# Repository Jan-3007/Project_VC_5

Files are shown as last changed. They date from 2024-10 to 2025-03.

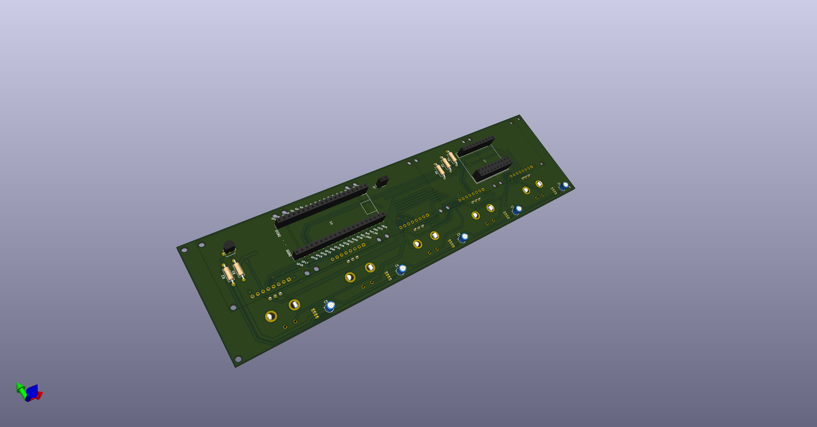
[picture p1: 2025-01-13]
Hardware/schematic/VC5_3D_model_v2.png

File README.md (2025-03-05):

# Project VC 5

Note: This project is the base for my upcoming project VC 5 and won't be updated anymore. Please see ... for an up-to-date version.

## General description
The aim of this project is to create an external device, which allows the user to adjust a variety of settings (e.g. volume, display brightness, settings within a program, ...) on a host PC. 

## Hardware
A number of rotaries are available as input (number set to 5 within the config file of this project) and LED's and displays to show any kind of status.
The schematic for the device can be found at _Harware/schematic_.

## Software
The software consists of two parts.

### 1. Firmware
The firmware is written for the Raspberry Pi RP2040. It communicates via USB with the host PC. The firmware only transmits data from the rotaries to the host PC and executes commands from the host PC. These commands can for example set the color of the LED and change the content shown on the displays.

### 2. PC application
  The PC application (only Windows) acts as the executing intelligence. It takes the data from the rotaries and processes it. In this case, as a demo, the volume of five different artificial audio channels is controlled. The application can also send commands to the device to e.g. set the LED color or write information on the displays.

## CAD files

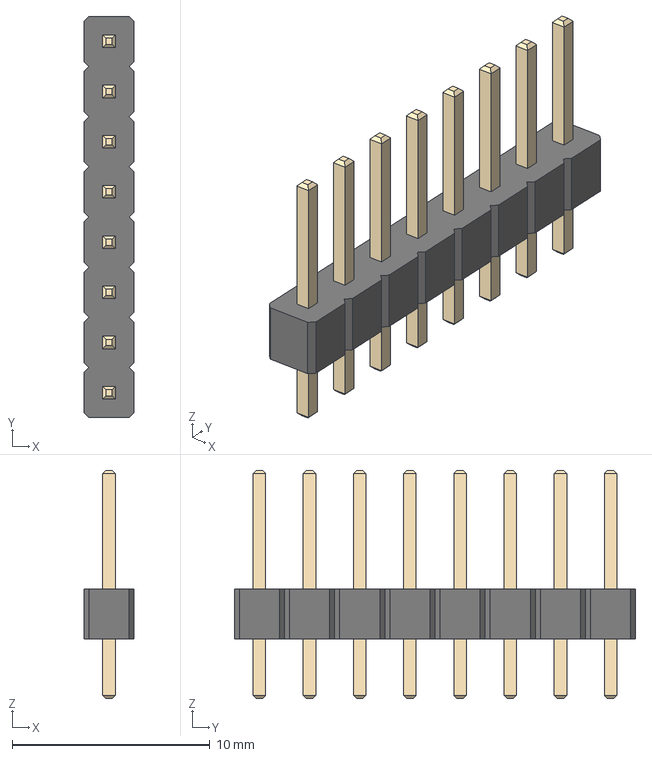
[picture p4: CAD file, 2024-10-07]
Hardware/3D_model/Display_PinHeader_1x08_P2.54mm_Vertical.step
2.54 x 20.3 x 11.5 mm

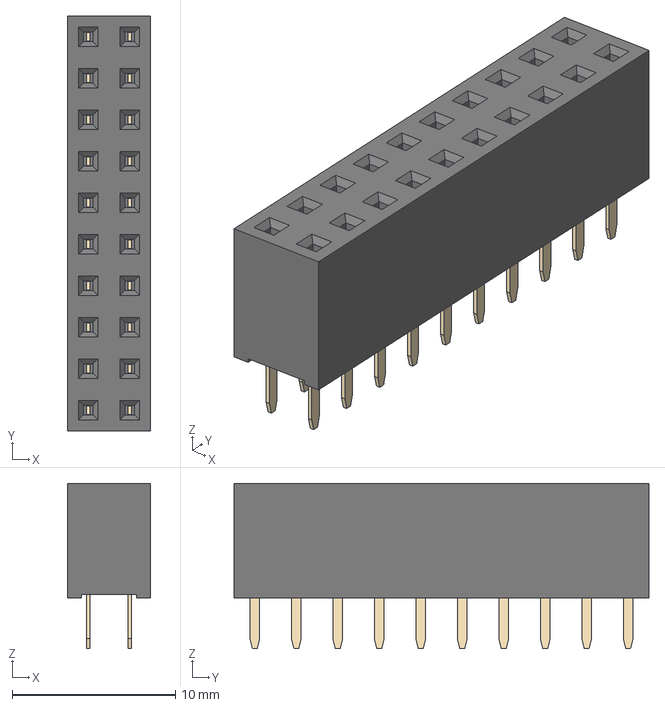
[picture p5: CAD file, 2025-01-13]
Hardware/schematic/VC5_schematic/PinSocket_2x10_P2.54mm_Vertical.step
5.08 x 25.4 x 10.1 mm

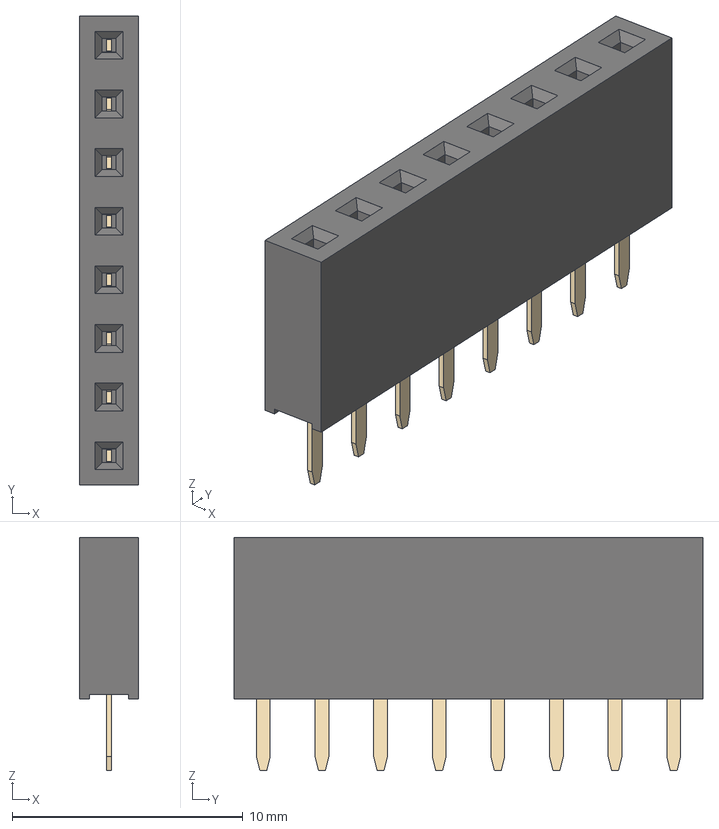
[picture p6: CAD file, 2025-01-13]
Hardware/schematic/VC5_schematic/PinSocket_1x08_P2.54mm_Vertical.step
2.54 x 20.3 x 10.1 mm

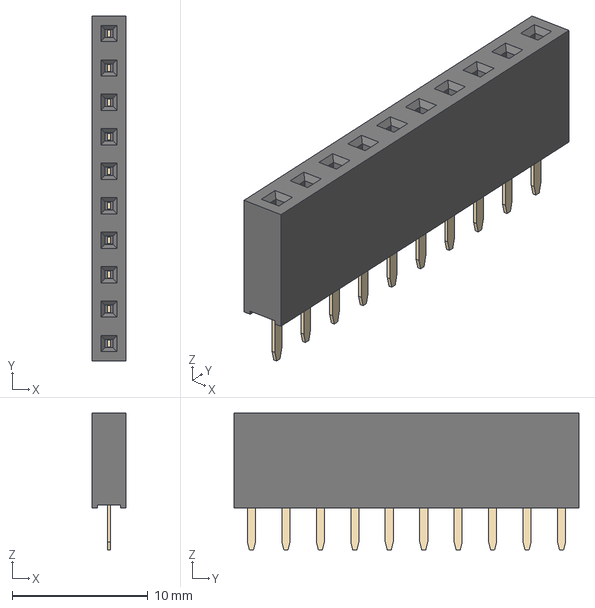
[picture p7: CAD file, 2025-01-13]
Hardware/schematic/VC5_schematic/PinSocket_1x10_P2.54mm_Vertical.step
2.54 x 25.4 x 10.1 mm

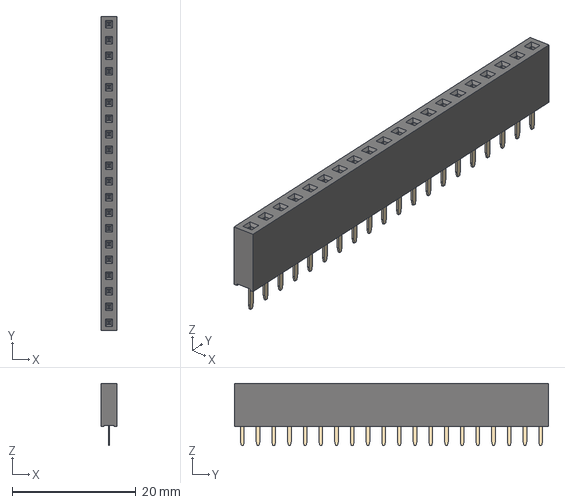
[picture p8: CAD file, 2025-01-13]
Hardware/schematic/VC5_schematic/PinSocket_1x20_P2.54mm_Vertical.step
2.54 x 50.8 x 10.1 mm

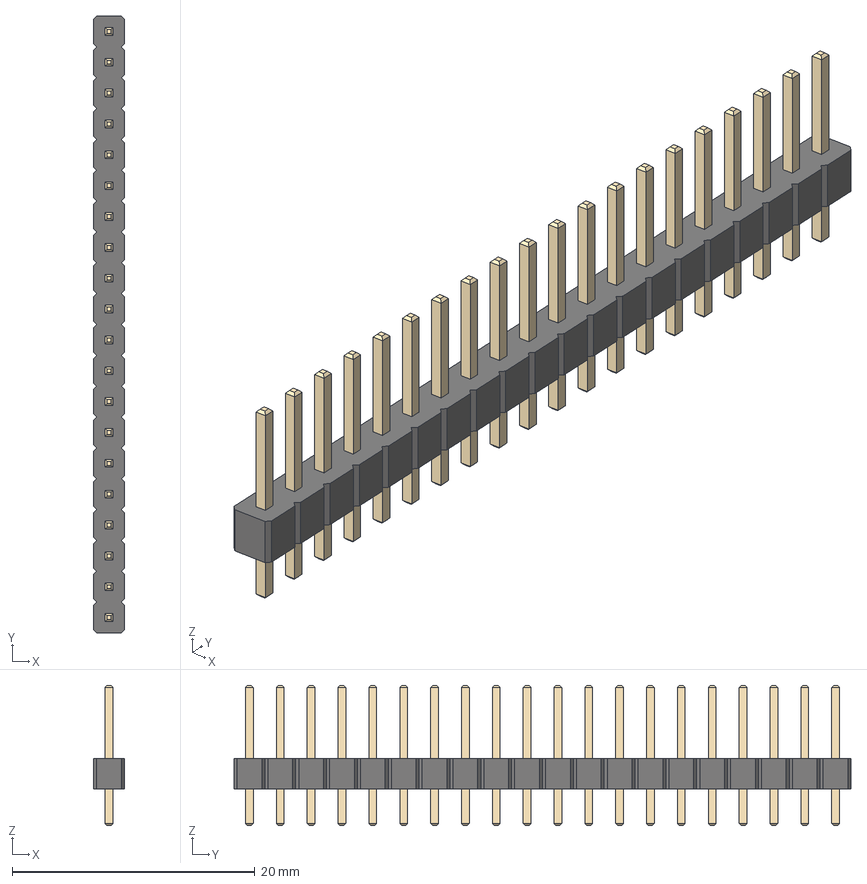
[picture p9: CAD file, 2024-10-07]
Hardware/schematic/VC5_schematic/Pico_PinHeader_1x20_P2.54mm_Vertical.step
2.54 x 50.8 x 11.5 mm

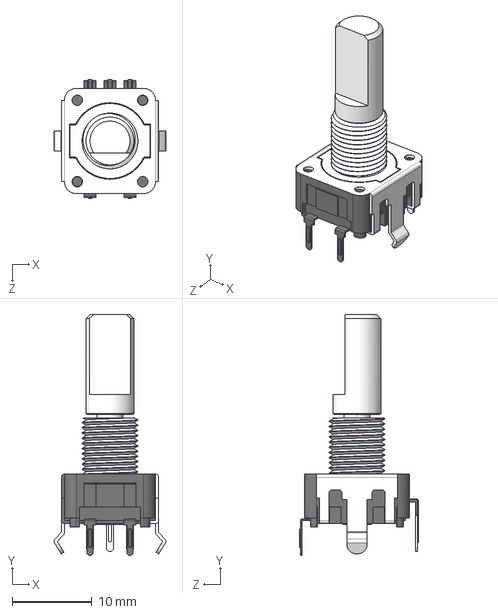
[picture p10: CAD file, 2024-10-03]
Hardware/schematic/VC5_schematic/PEC11R-4220F-S0024.stp
14.0 x 30.2 x 14.9 mm

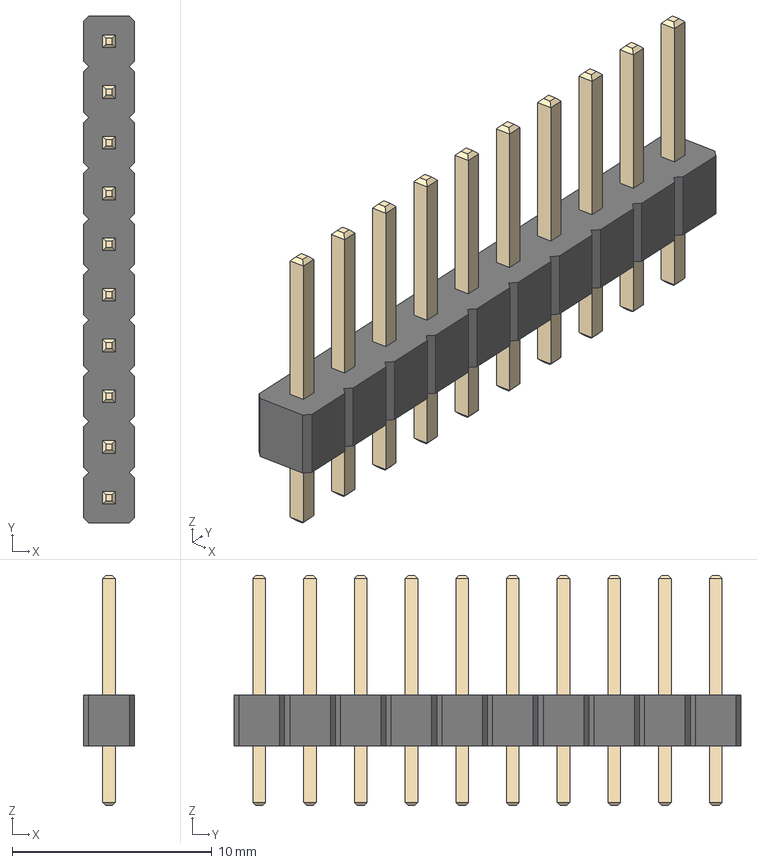
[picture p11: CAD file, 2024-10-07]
Hardware/schematic/VC5_schematic/MCP23017_PinHeader_1x10_P2.54mm_Vertical.step
2.54 x 25.4 x 11.5 mm

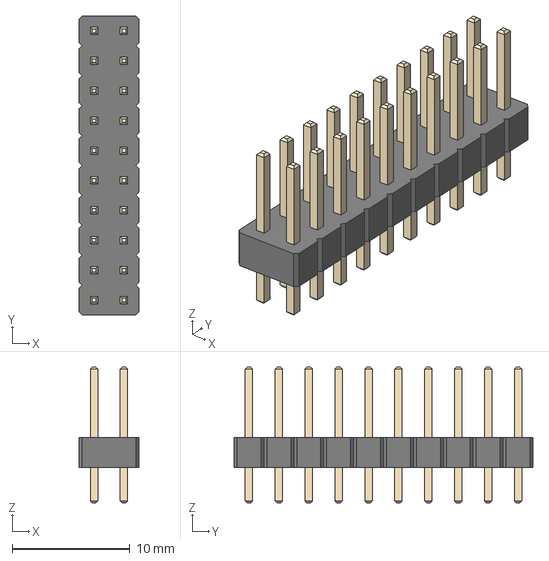
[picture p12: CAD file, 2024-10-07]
Hardware/schematic/VC5_schematic/MCP23017_PinHeader_2x10_P2.54mm_Vertical.step
5.08 x 25.4 x 11.5 mm

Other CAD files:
Hardware/schematic/VC5_schematic/Bourns/PEC11R-4220F-S0024/Allegro/pec11r4220fs0024.psm
Hardware/schematic/VC5_schematic/Bourns/PEC11R-4220F-S0024/DEHDL/pec11r_4220f_s0024/chips/chips.prt

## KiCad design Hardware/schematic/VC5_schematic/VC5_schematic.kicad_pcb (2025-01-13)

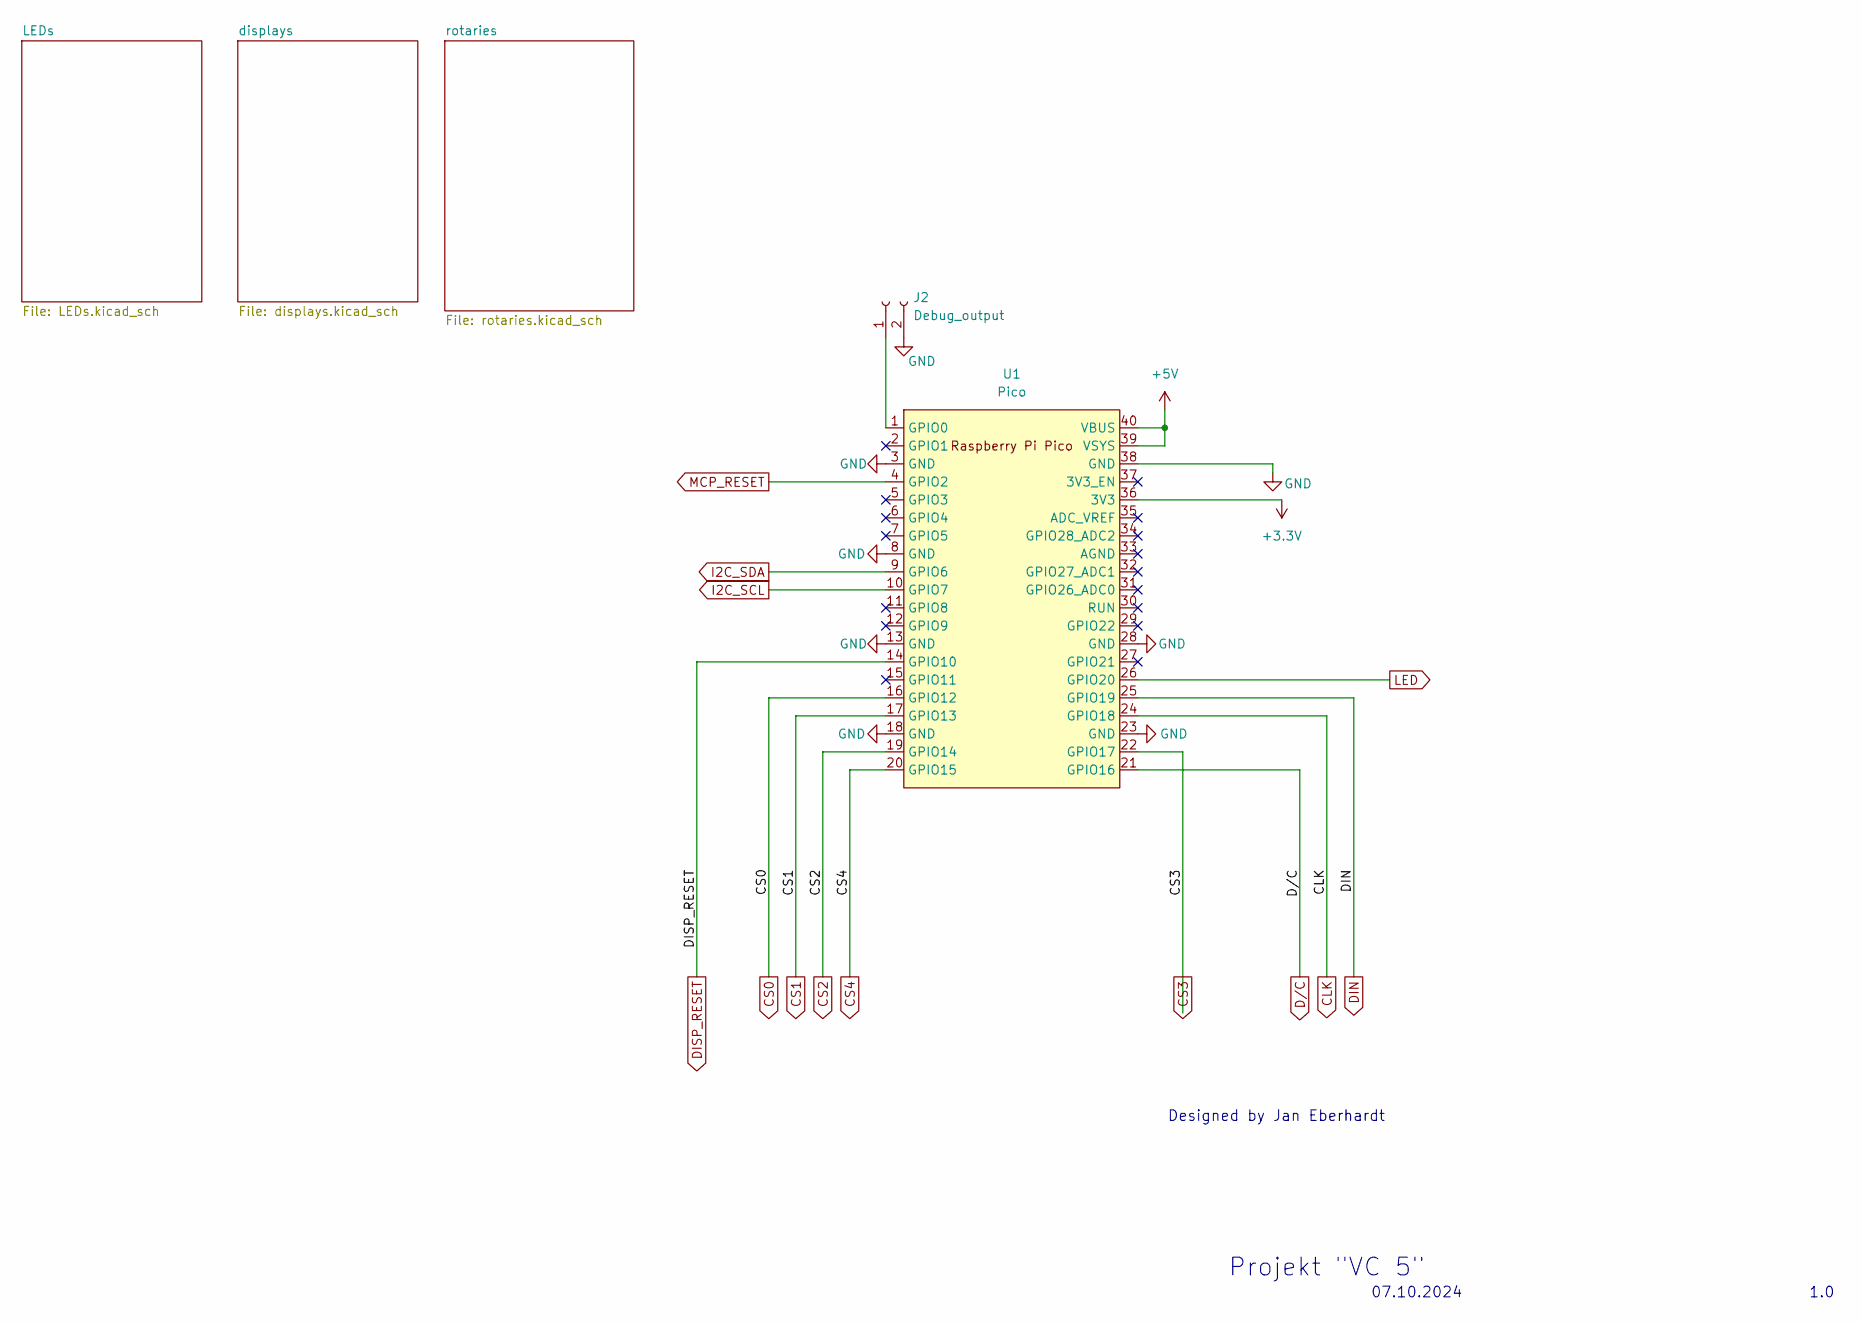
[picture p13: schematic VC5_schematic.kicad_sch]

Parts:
J2: Debug_output; PinSocket_1x02_P2.54mm_Vertical
U1: Pico; RPi_Pico_THT

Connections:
+3.3V: U1.36 (3V3); also elsewhere on the board
+5V: U1.39 (VSYS), U1.40 (VBUS); also elsewhere on the board
CLK: U1.24 (GPIO18); also elsewhere on the board
CS0: U1.16 (GPIO12); also elsewhere on the board
CS1: U1.17 (GPIO13); also elsewhere on the board
CS2: U1.19 (GPIO14); also elsewhere on the board
CS3: U1.22 (GPIO17); also elsewhere on the board
CS4: U1.20 (GPIO15); also elsewhere on the board
DIN: U1.25 (GPIO19); also elsewhere on the board
DISP_RESET: U1.14 (GPIO10); also elsewhere on the board
D/C: U1.21 (GPIO16); also elsewhere on the board
GND: J2.2, U1.3 (GND), U1.8 (GND), U1.13 (GND), U1.18 (GND), U1.23 (GND), U1.28 (GND), U1.38 (GND); also elsewhere on the board
I2C_SCL: U1.10 (GPIO7); also elsewhere on the board
I2C_SDA: U1.9 (GPIO6); also elsewhere on the board
LED: U1.26 (GPIO20); also elsewhere on the board
MCP_RESET: U1.4 (GPIO2); also elsewhere on the board
unnamed: J2.1, U1.1 (GPIO0)

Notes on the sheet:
Projekt "VC 5"
1.0
Designed by Jan Eberhardt
07.10.2024

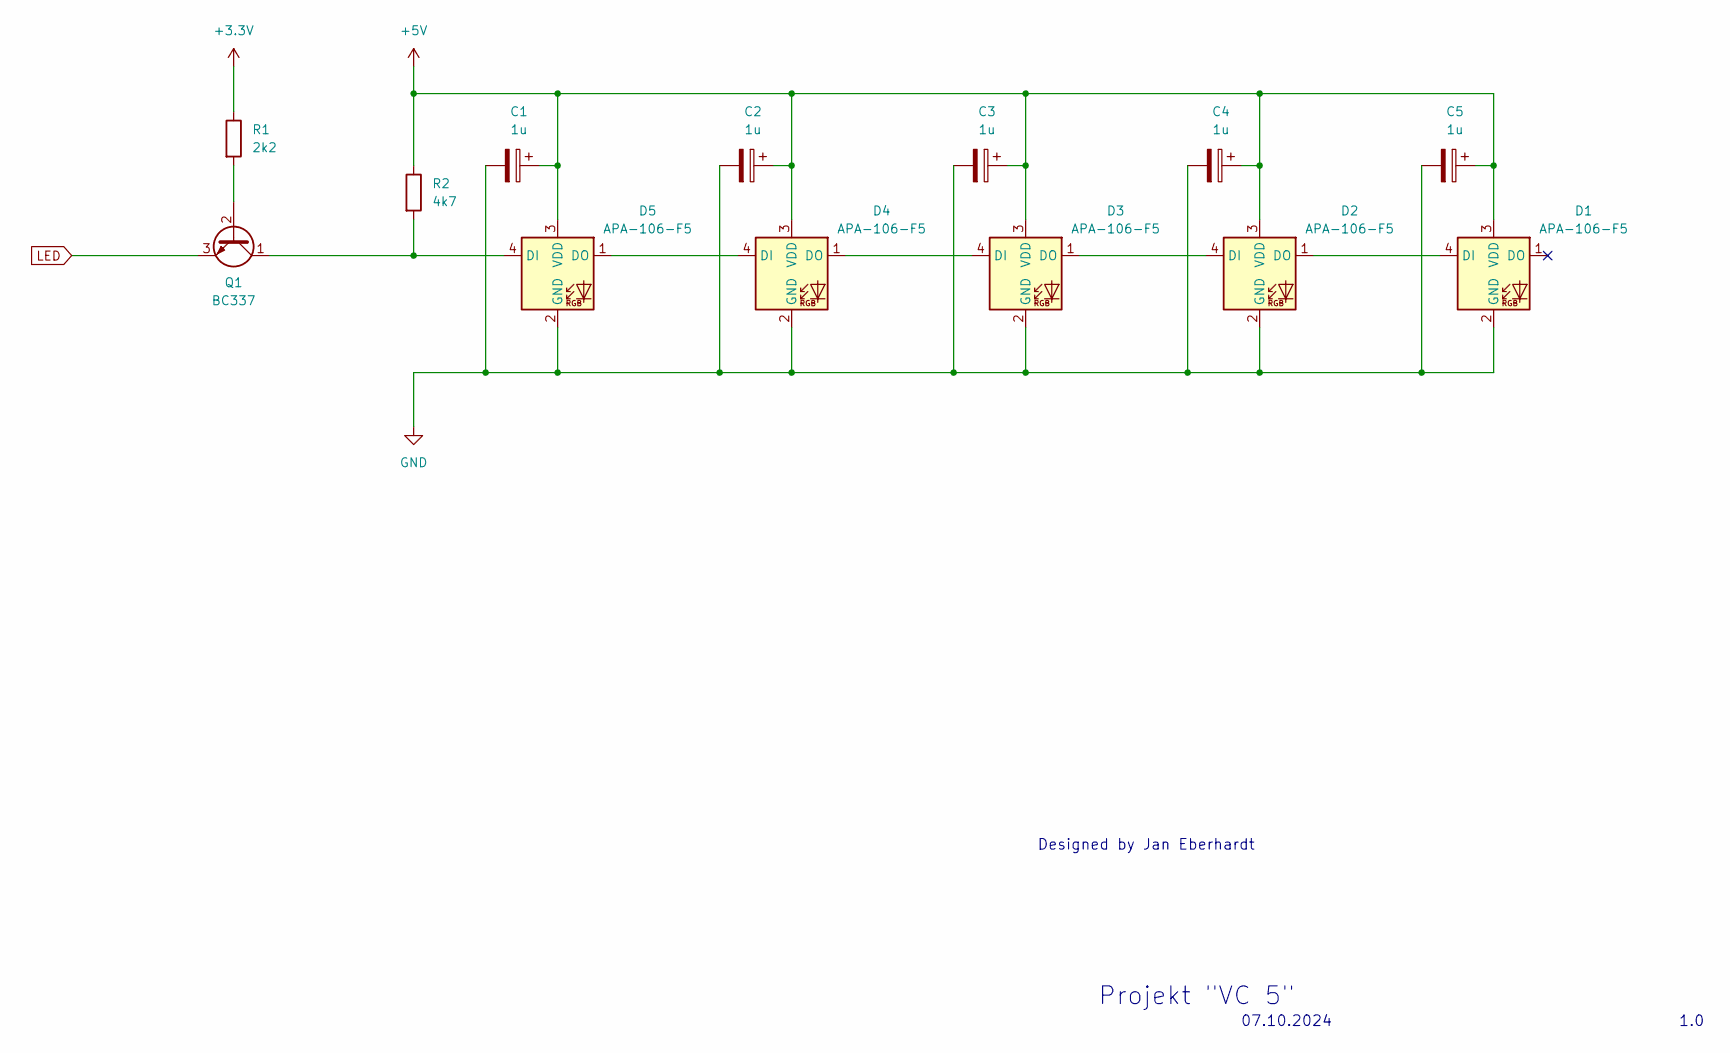
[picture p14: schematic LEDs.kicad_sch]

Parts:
C1, C2, C3, C4, C5: 1u; CP_Radial_D4.0mm_P1.50mm
D1, D2, D3, D4, D5: APA-106-F5; LED_D5.0mm-4_RGB
Q1: BC337; TO-92_Inline_Wide
R1: 2k2; R_Axial_DIN0207_L6.3mm_D2.5mm_P10.16mm_Horizontal
R2: 4k7; R_Axial_DIN0207_L6.3mm_D2.5mm_P10.16mm_Horizontal

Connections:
+3.3V: R1.1; also elsewhere on the board
+5V: C1.1, C2.1, C3.1, C4.1, C5.1, D1.3 (VDD), D2.3 (VDD), D3.3 (VDD), D4.3 (VDD), D5.3 (VDD), R2.1; also elsewhere on the board
GND: C1.2, C2.2, C3.2, C4.2, C5.2, D1.2 (GND), D2.2 (GND), D3.2 (GND), D4.2 (GND), D5.2 (GND); also elsewhere on the board
LED: Q1.3 (E); also elsewhere on the board
unnamed: D1.4 (DI), D2.1 (DO)
unnamed: D2.4 (DI), D3.1 (DO)
unnamed: D3.4 (DI), D4.1 (DO)
unnamed: D4.4 (DI), D5.1 (DO)
unnamed: D5.4 (DI), Q1.1 (C), R2.2
unnamed: Q1.2 (B), R1.2

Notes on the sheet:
Designed by Jan Eberhardt
Projekt "VC 5"
07.10.2024
1.0

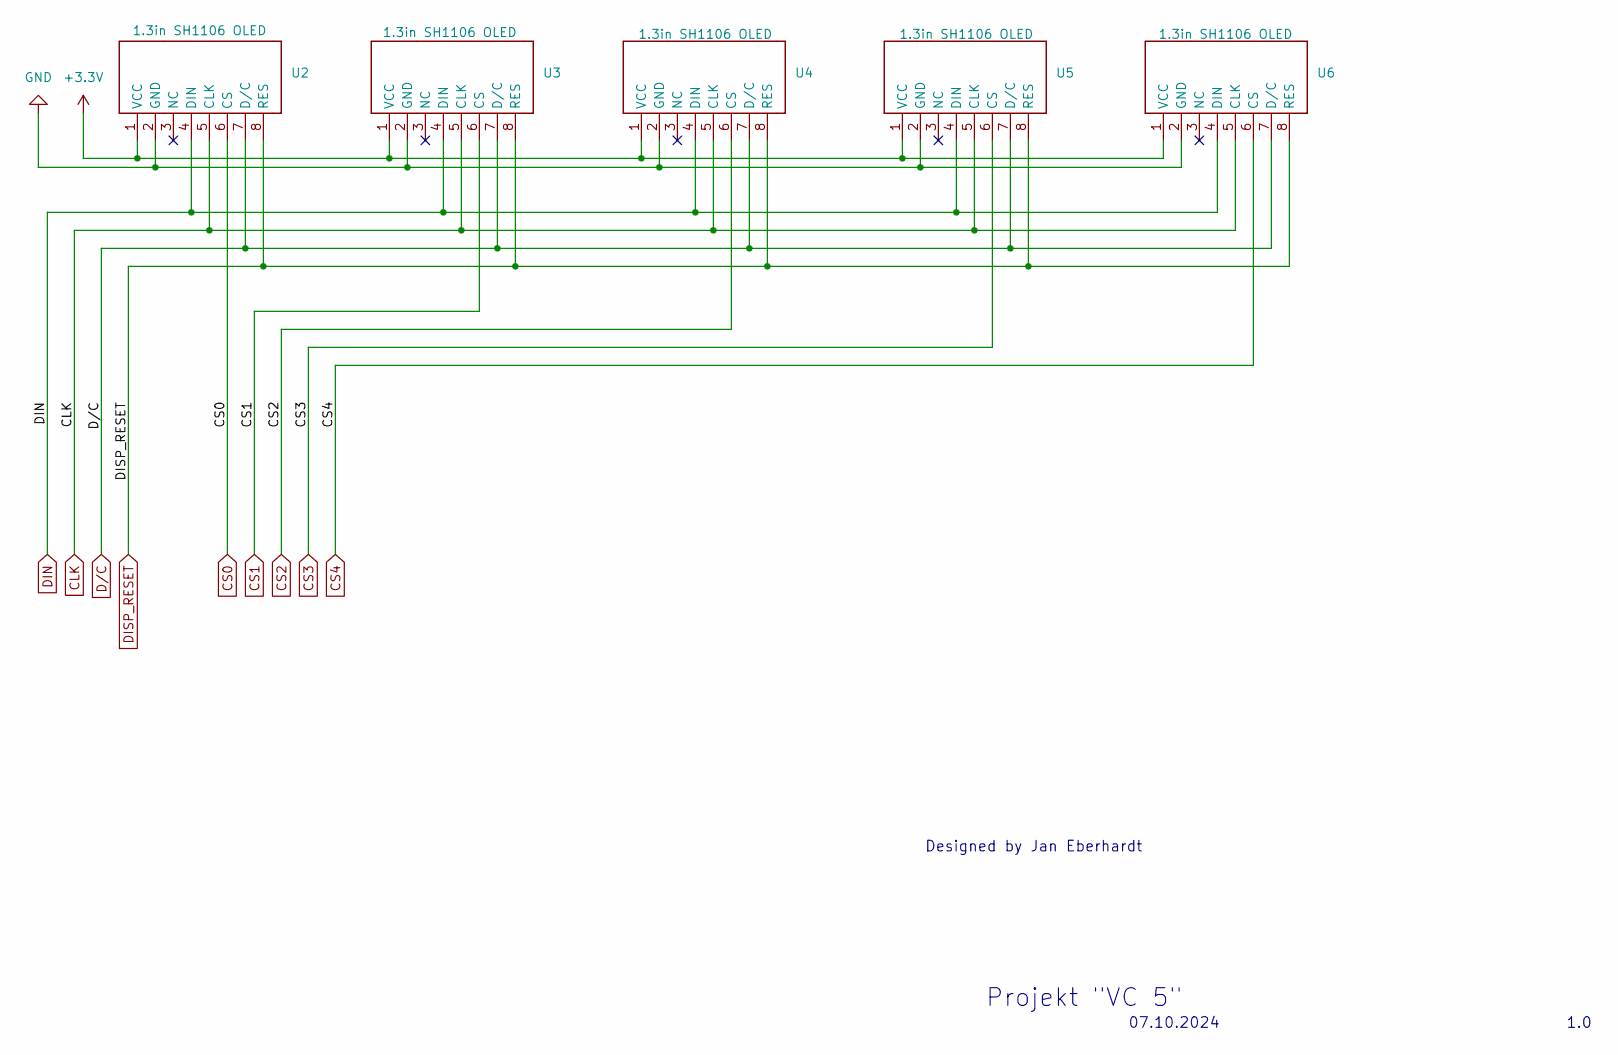
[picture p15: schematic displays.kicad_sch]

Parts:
U2, U3, U4, U5, U6: 1.3in SH1106 OLED; WaveShare_1in3_OLED_SH1106

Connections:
+3.3V: U2.1 (VCC), U3.1 (VCC), U4.1 (VCC), U5.1 (VCC), U6.1 (VCC); also elsewhere on the board
CLK: U2.5 (CLK), U3.5 (CLK), U4.5 (CLK), U5.5 (CLK), U6.5 (CLK); also elsewhere on the board
CS0: U2.6 (CS); also elsewhere on the board
CS1: U3.6 (CS); also elsewhere on the board
CS2: U4.6 (CS); also elsewhere on the board
CS3: U5.6 (CS); also elsewhere on the board
CS4: U6.6 (CS); also elsewhere on the board
DIN: U2.4 (DIN), U3.4 (DIN), U4.4 (DIN), U5.4 (DIN), U6.4 (DIN); also elsewhere on the board
DISP_RESET: U2.8 (RES), U3.8 (RES), U4.8 (RES), U5.8 (RES), U6.8 (RES); also elsewhere on the board
D/C: U2.7 (D/C), U3.7 (D/C), U4.7 (D/C), U5.7 (D/C), U6.7 (D/C); also elsewhere on the board
GND: U2.2 (GND), U3.2 (GND), U4.2 (GND), U5.2 (GND), U6.2 (GND); also elsewhere on the board

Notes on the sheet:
Designed by Jan Eberhardt
07.10.2024
Projekt "VC 5"
1.0

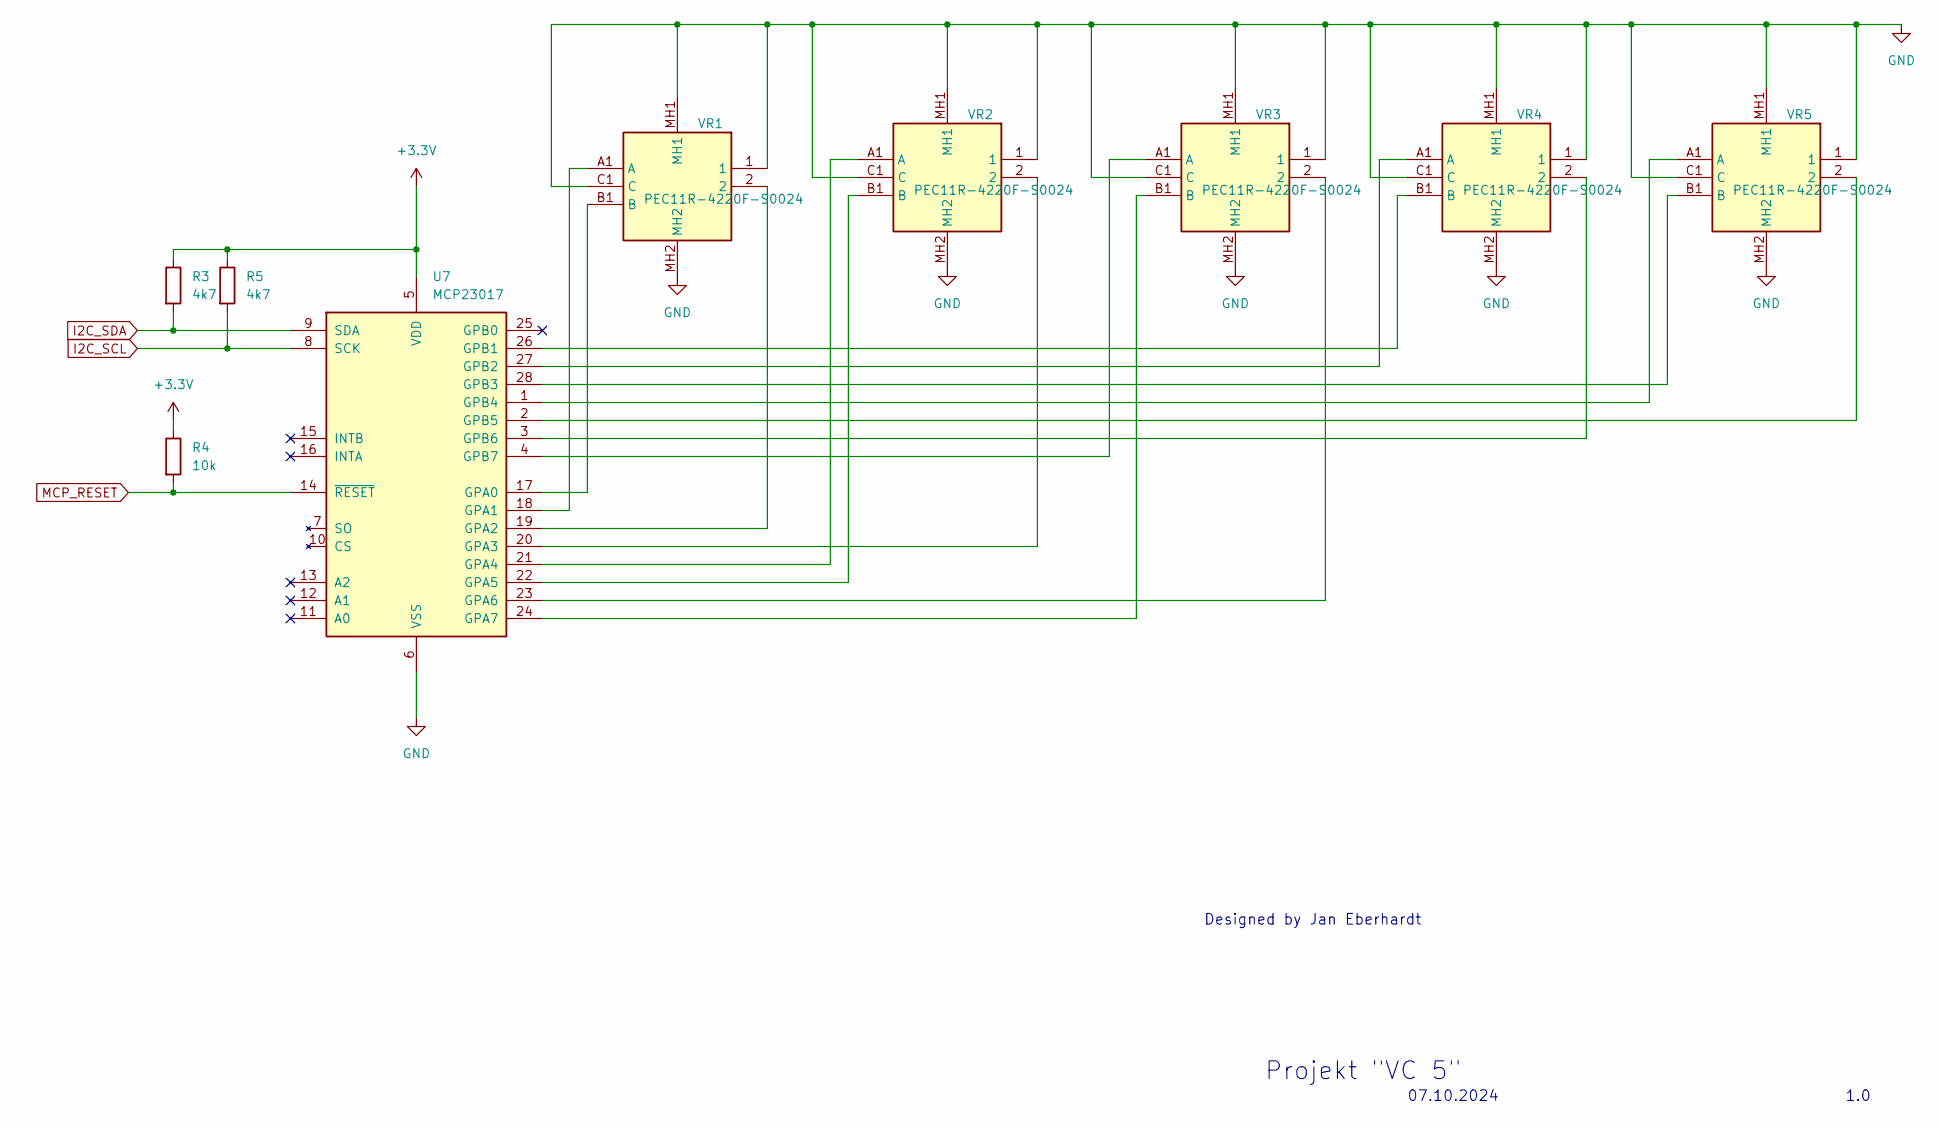
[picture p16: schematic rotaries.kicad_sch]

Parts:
R3, R5: 4k7; R_Axial_DIN0207_L6.3mm_D2.5mm_P10.16mm_Horizontal
R4: 10k; R_Axial_DIN0207_L6.3mm_D2.5mm_P10.16mm_Horizontal
U7: MCP23017; MCP23017_IO_expander
VR1, VR2, VR3, VR4, VR5: PEC11R-4220F-S0024; PEC11R4220FS0024; Manufacturer_Part_Number PEC11R-4220F-S0024; Mouser Part Number 652-PEC11R-4220F-S24

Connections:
+3.3V: R3.1, R4.1, R5.1, U7.5 (VDD); also elsewhere on the board
GND: U7.6 (VSS), VR1.1, VR1.C1 (C), VR1.MH1, VR1.MH2, VR2.1, VR2.C1 (C), VR2.MH1, VR2.MH2, VR3.1, VR3.C1 (C), VR3.MH1, VR3.MH2, VR4.1, VR4.C1 (C), VR4.MH1, VR4.MH2, VR5.1, VR5.C1 (C), VR5.MH1, VR5.MH2; also elsewhere on the board
I2C_SCL: R5.2, U7.8 (SCK); also elsewhere on the board
I2C_SDA: R3.2, U7.9 (SDA); also elsewhere on the board
MCP_RESET: R4.2, U7.14 (~RESET); also elsewhere on the board
unnamed: U7.17 (GPA0), VR1.B1 (B)
unnamed: U7.18 (GPA1), VR1.A1 (A)
unnamed: U7.19 (GPA2), VR1.2
unnamed: U7.20 (GPA3), VR2.2
unnamed: U7.21 (GPA4), VR2.A1 (A)
unnamed: U7.22 (GPA5), VR2.B1 (B)
unnamed: U7.23 (GPA6), VR3.2
unnamed: U7.24 (GPA7), VR3.B1 (B)
unnamed: U7.26 (GPB1), VR4.B1 (B)
unnamed: U7.27 (GPB2), VR4.A1 (A)
unnamed: U7.28 (GPB3), VR5.B1 (B)
unnamed: U7.1 (GPB4), VR5.A1 (A)
unnamed: U7.2 (GPB5), VR5.2
unnamed: U7.3 (GPB6), VR4.2
unnamed: U7.4 (GPB7), VR3.A1 (A)

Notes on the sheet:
Designed by Jan Eberhardt
07.10.2024
1.0
Projekt "VC 5"

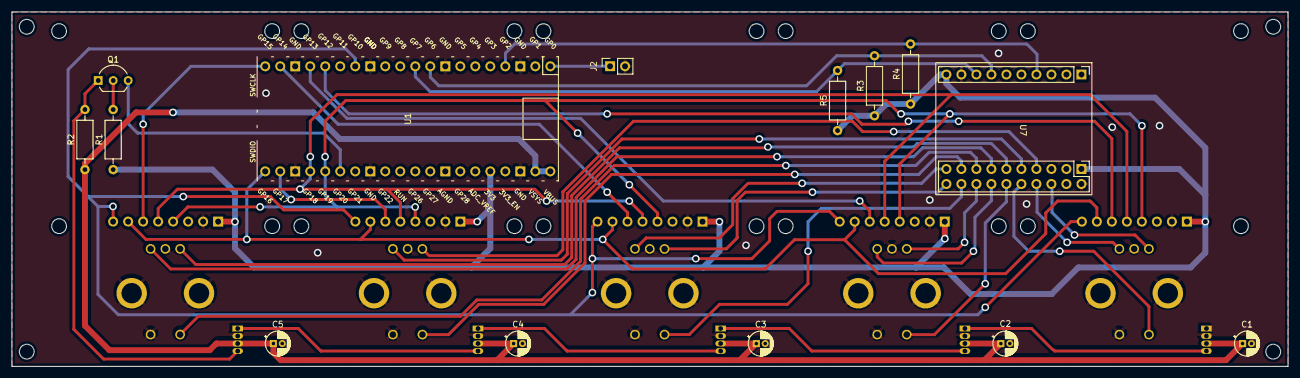
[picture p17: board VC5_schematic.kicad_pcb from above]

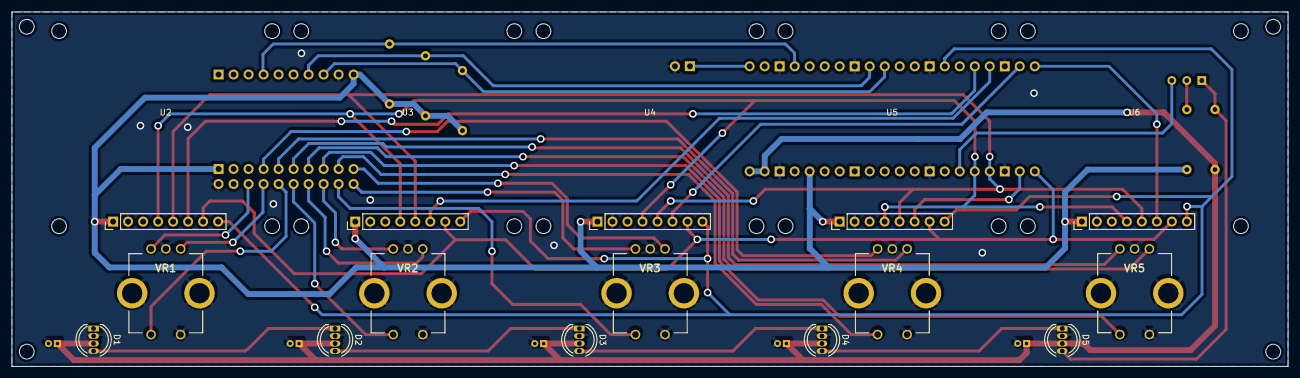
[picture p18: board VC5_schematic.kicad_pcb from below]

Board: 2 copper layers, 216.0 x 60.0 mm, 29 parts (15 on the bottom side), 38 nets.

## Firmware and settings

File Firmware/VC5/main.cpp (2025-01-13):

#include "VC5_global.h"



#ifdef __cplusplus
extern "C"
#endif
void fatal_error(int reason)
{
    printf("FATAL ERROR: reason %d", reason);

    while(true);
}



int main()
{
    stdio_init_all();
    printf("VC 5: %s %s\n", __DATE__, __TIME__);

    init_i2c();
    init_spi();

    // init and task setup for the rotaries
    init_rotaries();

    // init PIO for LEDs
    init_led_chain();

    // init displays
    init_displays();

    // init and task setup for USB
    init_usb();



    /* Start the scheduler. */
    vTaskStartScheduler();

    for( ; ; )
    {
        /* Should not reach here. */
    }

    return 0;
}

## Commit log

2024-10-01 created schematic
    [LEDs.kicad_sch, VC5_schematic.kicad_pcb, VC5_schematic.kicad_sch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]
2024-10-02 added the Pico SDK
2024-10-02 include Pico SDK in to the project
2024-10-02 updated display values
    [displays.kicad_sch]
2024-10-03 minor updates to the schematic
    [LEDs.kicad_sch, VC5_schematic.kicad_sch, displays.kicad_sch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]
2024-10-03 added missing footprints, changed schematic symbols for the rotaries
    [EDI2CAP.CFG, LEDs.kicad_sch, PEC11R-4220F-S0024.stp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]
2024-10-07 first layout
    [Display_PinHeader_1x08_P2.54mm_Vertical.step, LEDs.kicad_sch, MCP23017_PinHeader_1x10_P2.54mm_Vertical.step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]
2024-10-07 included Pico SDK and FreeRTOS
2024-10-10 reworked the PCB layout
    [LEDs.kicad_sch, PinSocket_1x08_P2.54mm_Vertical.step, PinSocket_1x10_P2.54mm_Vertical.step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]
2024-10-10 added 3D models from KiCAD to the new FreeCAD project
    [Display_PinHeader_1x08_P2.54mm_Vertical.step]
2024-10-11 resolved some change errors and tested FreeRTOS
    [main.cpp]
2024-10-11 small adjustments to the positions of the components
    [VC5_schematic.kicad_pcb]
2024-10-11 updated the 3D models from KiCAD
2024-10-14 implemented basic functions for using I2C
2024-12-26 changed from HID to USB Vendor specific device, which will now send rotary states to USB host
2024-12-26 implemented aquisition of device and interface handles inside of the main function
2024-12-26 improved comments and error prints
    [main.cpp]
2024-12-29 pressing the rotary button now controls the color of the corresponding LED
2025-01-02 Displays are now controlled by the WinApp via rotaries and show current state.
2025-01-13 disabled debug prints

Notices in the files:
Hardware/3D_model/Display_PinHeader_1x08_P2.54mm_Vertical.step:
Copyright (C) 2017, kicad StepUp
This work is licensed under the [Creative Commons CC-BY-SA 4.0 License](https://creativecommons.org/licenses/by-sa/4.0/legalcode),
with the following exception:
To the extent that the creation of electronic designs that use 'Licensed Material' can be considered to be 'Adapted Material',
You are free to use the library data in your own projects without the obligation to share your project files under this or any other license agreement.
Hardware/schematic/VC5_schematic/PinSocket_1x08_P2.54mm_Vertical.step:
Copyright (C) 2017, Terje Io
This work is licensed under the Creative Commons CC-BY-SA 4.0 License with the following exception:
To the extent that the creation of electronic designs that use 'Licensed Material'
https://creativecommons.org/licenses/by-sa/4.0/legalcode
